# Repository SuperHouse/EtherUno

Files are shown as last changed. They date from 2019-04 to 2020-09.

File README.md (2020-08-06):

SuperHouse EtherUNO
===================

The EtherUNO is a 100% Arduino Compatible Board, based on the Arduino
UNO reference design, but with improvements and updates for ease of use,
cost, and getting started. It also includes on-board Ethernet with PoE
(Power-over-Ethernet) support and uses a USB-C socket.

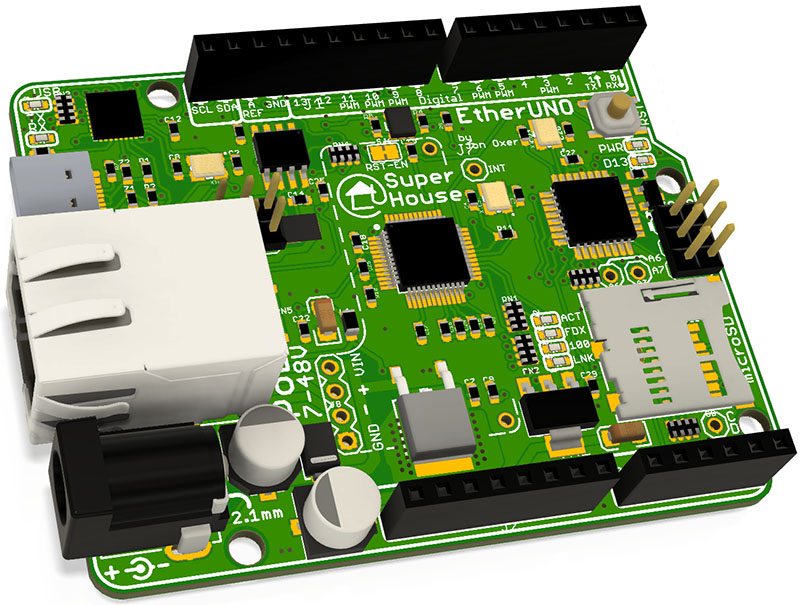
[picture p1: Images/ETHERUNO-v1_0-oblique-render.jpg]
EtherUNO


Features:

 * LEDs visible on the edge
 * USB-C Connector
 * I2C MAC address ROM
 * Overlay guide where you need it (both top and bottom)
 * D13 pin works for everything
 * RX pin biased
 * Mounting holes

More information is available at:

  https://www.superhouse.tv/eu

Hardware
--------
The "Hardware" directory contains the PCB design as an EAGLE project.
EAGLE PCB design software is available from Autodesk free for
non-commercial use.

Credits
-------
 * Jonathan Oxer <jon@oxer.com.au>

 The EtherUNO is based on the EtherTen, which was designed by Jonathan
 Oxer and Marc Alexander.

License
-------
Copyright 2020 SuperHouse Automation Pty Ltd  www.superhouse.tv  

The hardware portion of this project is licensed under the TAPR Open
Hardware License (www.tapr.org/OHL). The "license" folder within this
repository contains a copy of this license in plain text format.

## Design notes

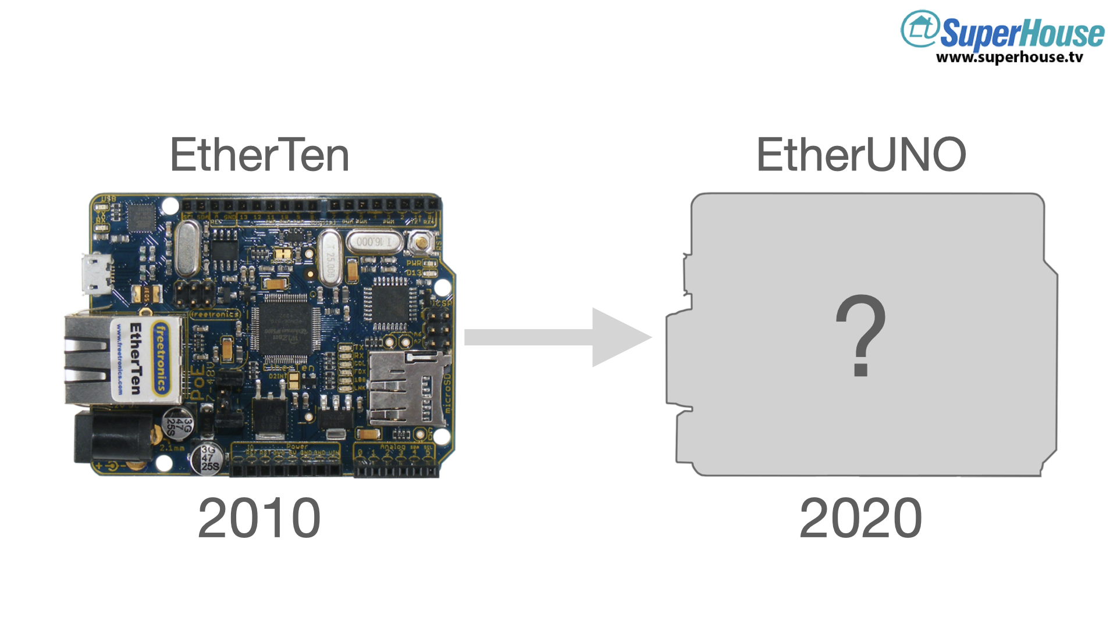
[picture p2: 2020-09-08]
Images/ETHERUNO-teaser/ETHERUNO-teaser.002.jpeg

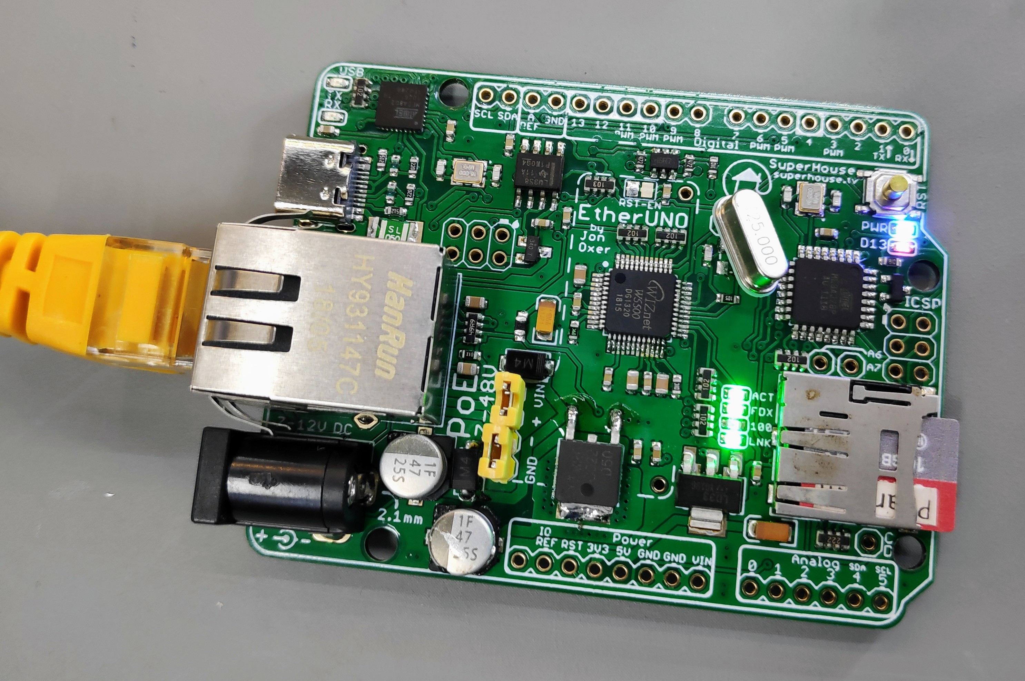
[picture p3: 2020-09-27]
Images/2020-09-27 17.50.06.jpg

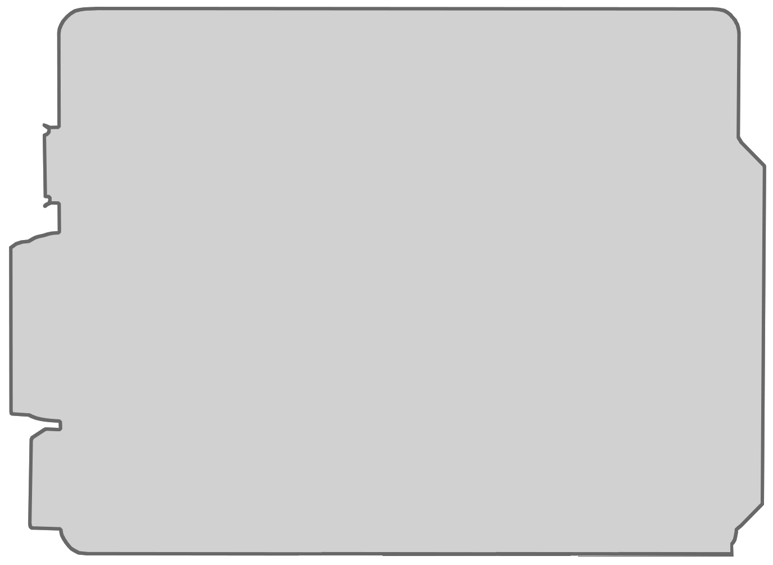
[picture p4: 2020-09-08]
Images/ET-v3_0-outline.png

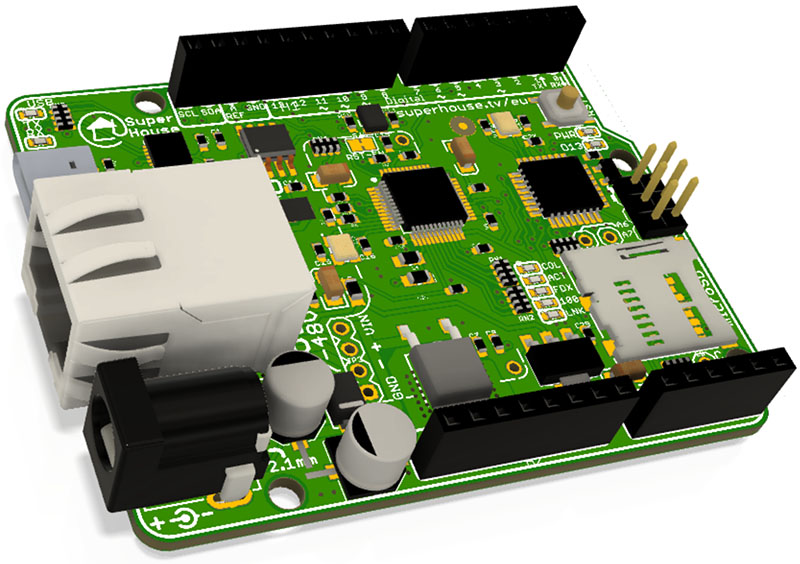
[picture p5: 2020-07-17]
Images/ETHERUNO-v4_0-oblique-render.jpg

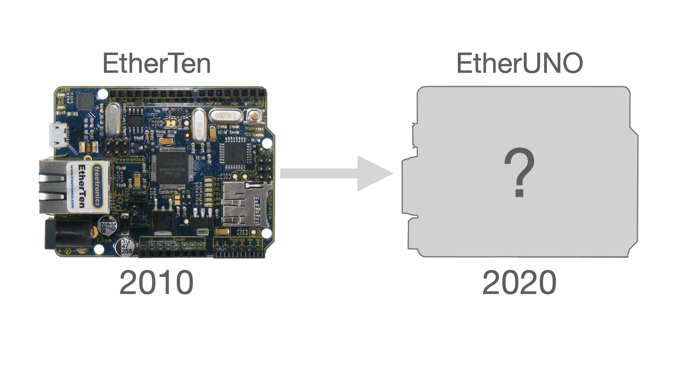
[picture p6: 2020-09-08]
Images/ETHERUNO-teaser/ETHERUNO-teaser.001.jpeg

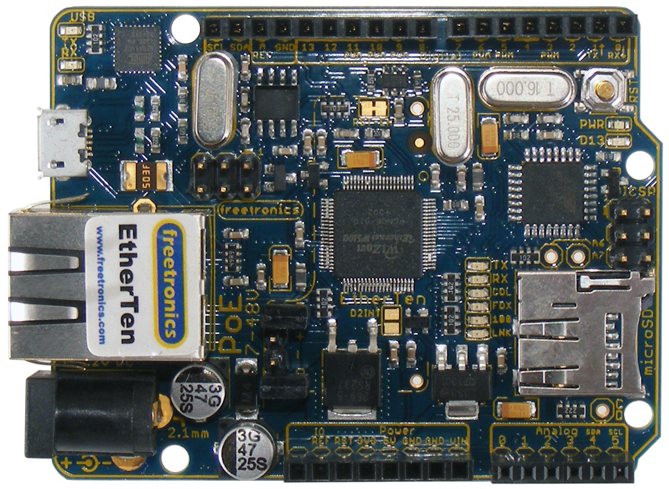
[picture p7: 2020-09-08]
Images/ET-v3_0-top.png

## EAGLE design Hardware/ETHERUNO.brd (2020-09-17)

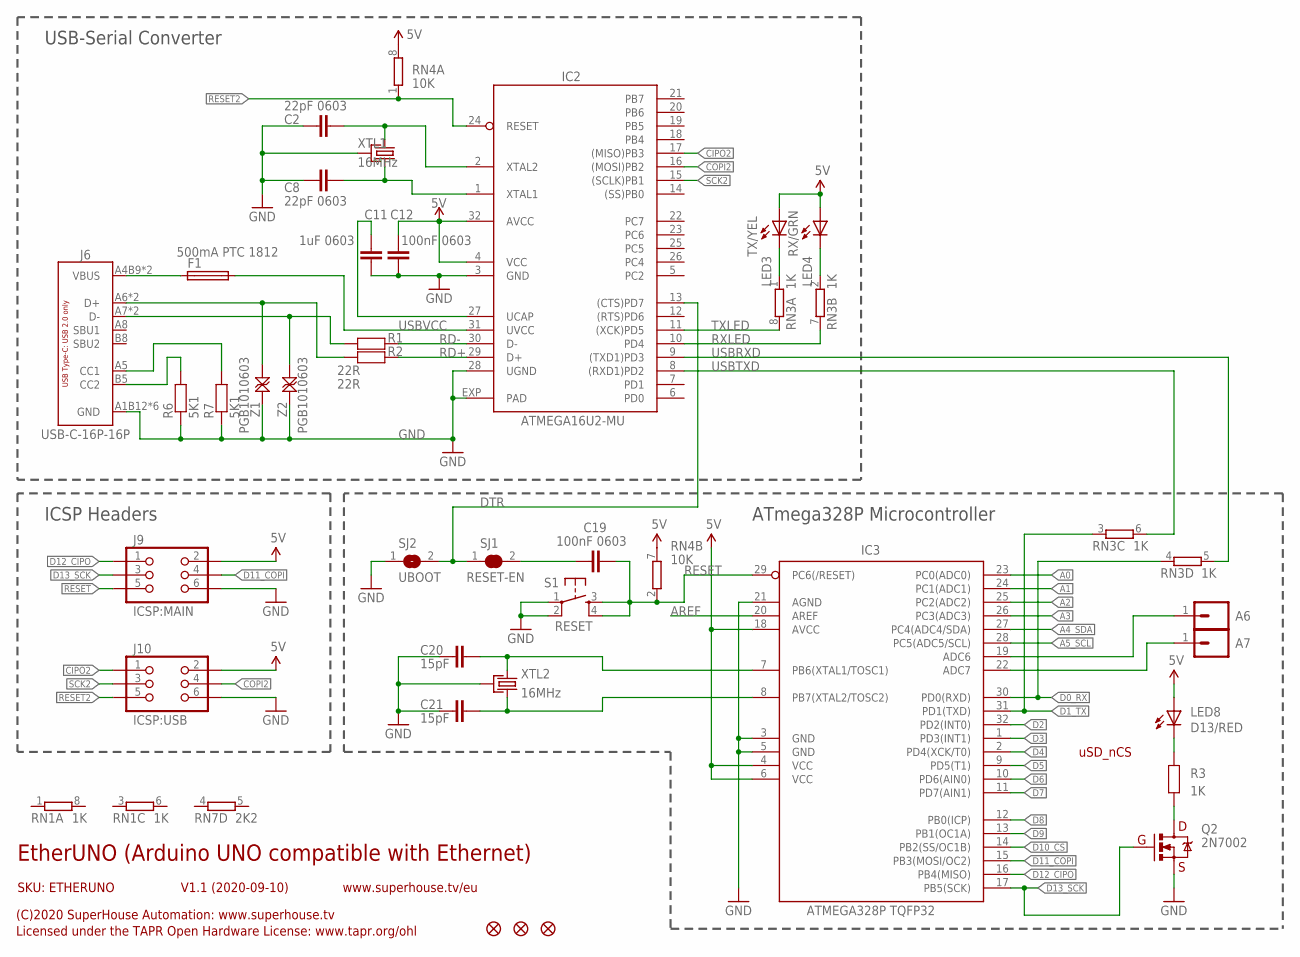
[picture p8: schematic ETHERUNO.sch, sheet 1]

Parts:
A6: A6; 1X01
A7: A7; 1X01
C2, C8: 22pF 0603; C0603
C11: 1uF 0603; C0603
C12, C19: 100nF 0603; C0603
C20, C21: 15pF; C0603
F1: 500mA PTC 1812; 1812
FID1, FID2, FID3: FIDUCIAL1X2.5; FIDUCIAL-1X2.5
IC2: ATMEGA16U2-MU; ATMEL_QFN32
IC3: ATMEGA328P TQFP32; TQFP32-08
J6: USB-C-16P-16P; USB-C-16P
J9: ICSP:MAIN; 2X03-ICSP
J10: ICSP:USB; 2X03-ICSP
LED3: TX/YEL; LED-0603
LED4: RX/GRN; LED-0603
LED8: D13/RED; LED-0603
Q2: 2N7002; SOT23-3
R1, R2: 22R; R0603
R3: 1K; R0603
R6, R7: 5K1; R0603
RN1, RN3: 1K; CAY16
RN4: 10K; CAY16
RN7: 2K2; CAY16
S1: RESET; TACTILE_SMT-6MM
SJ1: RESET-EN; SJC
SJ2: UBOOT; SJ
XTL1, XTL2: 16MHz; CRYSTAL-SMD-3X2
Z1, Z2: PGB1010603; TVS0603

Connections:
5V: C12.1, IC2.4 (VCC), IC2.32 (AVCC), IC3.4 (VCC), IC3.6 (VCC), IC3.18 (AVCC), J9.2, J10.2, LED3.A, LED4.A, LED8.A, RN4.7 (2), RN4.8 (2); also elsewhere on the board
A0: IC3.23 (PC0(ADC0)); also elsewhere on the board
A1: IC3.24 (PC1(ADC1)); also elsewhere on the board
A2: IC3.25 (PC2(ADC2)); also elsewhere on the board
A3: IC3.26 (PC3(ADC3)); also elsewhere on the board
A4_SDA: IC3.27 (PC4(ADC4/SDA)); also elsewhere on the board
A5_SCL: IC3.28 (PC5(ADC5/SCL)); also elsewhere on the board
AREF: IC3.20 (AREF); also elsewhere on the board
CIPO2: IC2.17 ((MISO)PB3), J10.1
COPI2: IC2.16 ((MOSI)PB2), J10.4
D0_RX: IC3.30 (PD0(RXD)), RN3.4 (1); also elsewhere on the board
D1_TX: IC3.31 (PD1(TXD)), RN3.3 (1); also elsewhere on the board
D2: IC3.32 (PD2(INT0)); also elsewhere on the board
D3: IC3.1 (PD3(INT1)); also elsewhere on the board
D4: IC3.2 (PD4(XCK/T0)); also elsewhere on the board
D5: IC3.9 (PD5(T1)); also elsewhere on the board
D6: IC3.10 (PD6(AIN0)); also elsewhere on the board
D7: IC3.11 (PD7(AIN1)); also elsewhere on the board
D8: IC3.12 (PB0(ICP)); also elsewhere on the board
D9: IC3.13 (PB1(OC1A)); also elsewhere on the board
D10_CS: IC3.14 (PB2(SS/OC1B)); also elsewhere on the board
D11_COPI: IC3.15 (PB3(MOSI/OC2)), J9.4; also elsewhere on the board
D12_CIPO: IC3.16 (PB4(MISO)), J9.1; also elsewhere on the board
D13_SCK: IC3.17 (PB5(SCK)), J9.3, Q2.1 (G); also elsewhere on the board
DTR: IC2.13 ((CTS)PD7), SJ1.1, SJ2.2
GND: C2.1, C8.1, C11.2, C12.2, C20.1, C21.1, IC2.3 (GND), IC2.28 (UGND), IC2.EXP (PAD), IC3.3 (GND), IC3.5 (GND), IC3.21 (AGND), J6.A1B12 (GND), J6.A12B1 (GND), J6.FIX1 (GND), J6.FIX2 (GND), J6.FIX3 (GND), J6.FIX4 (GND), J9.6, J10.6, Q2.2 (S), R6.1, R7.1, S1.1, S1.2, SJ2.1, XTL1.2 (GND), XTL1.4 (GND), XTL2.2 (GND), XTL2.4 (GND), Z1.2, Z2.2; also elsewhere on the board
unnamed: C20.2, IC3.7 (PB6(XTAL1/TOSC1)), XTL2.1
unnamed: C19.1, SJ1.2
unnamed: LED8.C, R3.2
unnamed: Q2.3 (D), R3.1
unnamed: C21.2, IC3.8 (PB7(XTAL2/TOSC2)), XTL2.3 (2)
unnamed: C8.2, IC2.1 (XTAL1), XTL1.3 (2)
unnamed: J6.B5 (CC2), R6.2
unnamed: LED4.C, RN3.2 (1)
unnamed: LED3.C, RN3.1
unnamed: J6.A6 (D+), J6.B6 (D+), R2.2, Z1.1
unnamed: J6.A7 (D-), J6.B7 (D-), R1.2, Z2.1
unnamed: A7.1, IC3.22 (ADC7)
unnamed: A6.1, IC3.19 (ADC6)
unnamed: J6.A5 (CC1), R7.2
unnamed: C2.2, IC2.2 (XTAL2), XTL1.1
unnamed: F1.1, J6.A4B9 (VBUS), J6.A9B4 (VBUS)
unnamed: C11.1, IC2.27 (UCAP)
RD+: IC2.29 (D+), R2.1
RD-: IC2.30 (D-), R1.1
RESET: C19.2, IC3.29 (PC6(/RESET)), J9.5, RN4.2 (1), S1.3, S1.4; also elsewhere on the board
RESET2: IC2.24 (RESET), J10.5, RN4.1
RXLED: IC2.10 (PD4), RN3.7 (2)
SCK2: IC2.15 ((SCLK)PB1), J10.3
TXLED: IC2.11 ((XCK)PD5), RN3.8 (2)
USBRXD: IC2.9 ((TXD1)PD3), RN3.5 (2)
USBTXD: IC2.8 ((RXD1)PD2), RN3.6 (2)
USBVCC: F1.2, IC2.31 (UVCC); also elsewhere on the board

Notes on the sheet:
uSD_nCS
EtherUNO (Arduino UNO compatible with Ethernet)
SKU: ETHERUNO
(C)2020 SuperHouse Automation: www.superhouse.tv
Licensed under the TAPR Open Hardware License: www.tapr.org/ohl
www.superhouse.tv/eu
V1.1 (2020-09-10)
ICSP Headers
USB-Serial Converter
ATmega328P Microcontroller

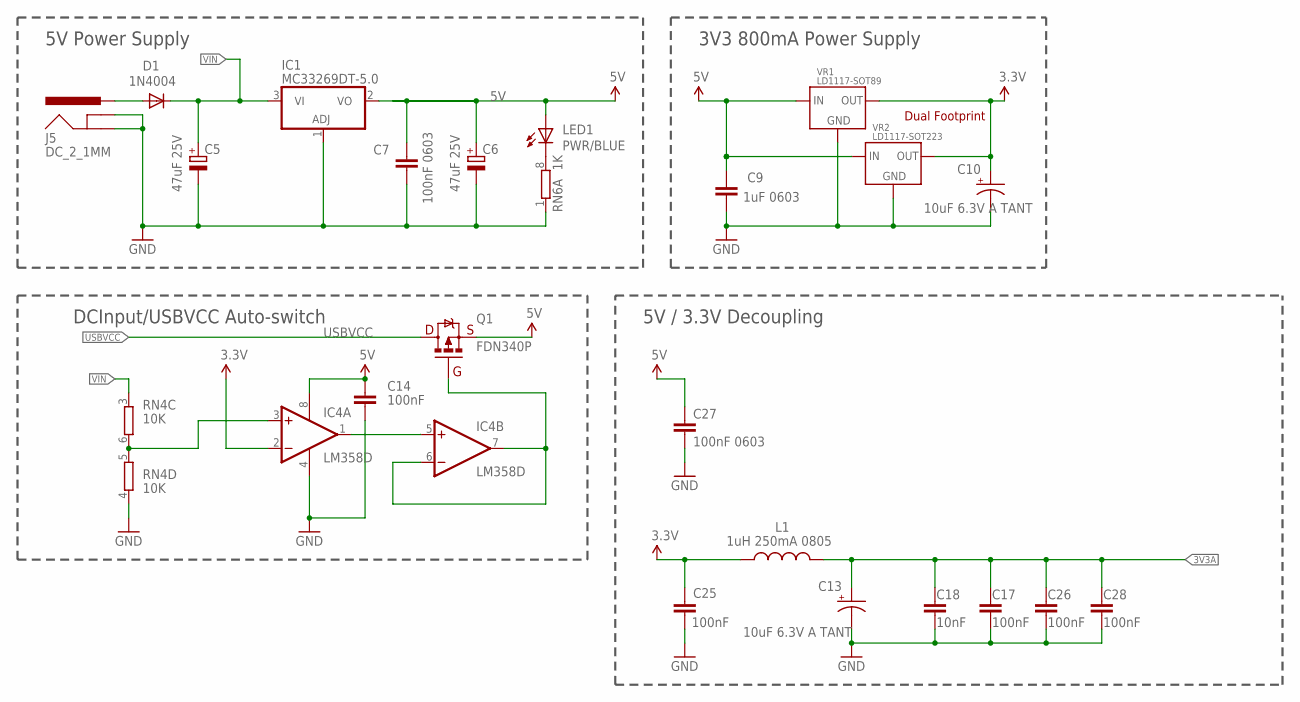
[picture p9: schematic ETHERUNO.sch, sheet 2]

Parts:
C5, C6: 47uF 25V; PANASONIC_D
C7, C27: 100nF 0603; C0603
C9: 1uF 0603; C0603
C10, C13: 10uF 6.3V A TANT; EIA3216
C14, C17, C25, C26, C28: 100nF; C0603
C18: 10nF; C0603
D1: 1N4004; SMA-DIODE
IC1: MC33269DT-5.0; DPACK
IC4: LM358D; SO08
J5: DC_2_1MM; POWER_JACK_SLOTS
L1: 1uH 250mA 0805; L2012C
LED1: PWR/BLUE; LED-0603
Q1: FDN340P; SOT23
RN4: 10K; CAY16
RN6: 1K; CAY16
VR1: LD1117-SOT89; SOT89
VR2: LD1117-SOT223; SOT-223

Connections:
3.3V: C10.A (+), C25.1, IC4.2 (-IN), L1.1, VR1.2 (OUT), VR1.4 (OUT), VR2.2 (OUT), VR2.4 (OUT); also elsewhere on the board
3V3A: C13.A (+), C17.1, C18.1, C26.1, C28.1, L1.2; also elsewhere on the board
5V: C6.+, C7.1, C9.1, C14.1, C27.1, IC1.2 (VO), IC4.8 (V+), LED1.A, Q1.2 (S), VR1.3 (IN), VR2.3 (IN); also elsewhere on the board
GND: C5.-, C6.-, C7.2, C9.2, C10.C (-), C13.C (-), C14.2, C17.2, C18.2, C25.2, C26.2, C27.2, C28.2, IC1.1 (ADJ), IC4.4 (V-), J5.GND, J5.GNDBREAK, RN4.4 (1), RN6.1, VR1.1 (GND), VR2.1 (GND); also elsewhere on the board
unnamed: IC4.3 (+IN), RN4.5 (2), RN4.6 (2)
unnamed: LED1.C, RN6.8 (2)
unnamed: IC4.6 (-IN), IC4.7 (OUT), Q1.1 (G)
unnamed: IC4.1 (OUT), IC4.5 (+IN)
unnamed: D1.A, J5.PWR
USBVCC: Q1.3 (D); also elsewhere on the board
VIN: C5.+, D1.C, IC1.3 (VI), RN4.3 (1); also elsewhere on the board

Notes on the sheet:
3V3 800mA Power Supply
Dual Footprint
5V Power Supply
DCInput/USBVCC Auto-switch
5V / 3.3V Decoupling

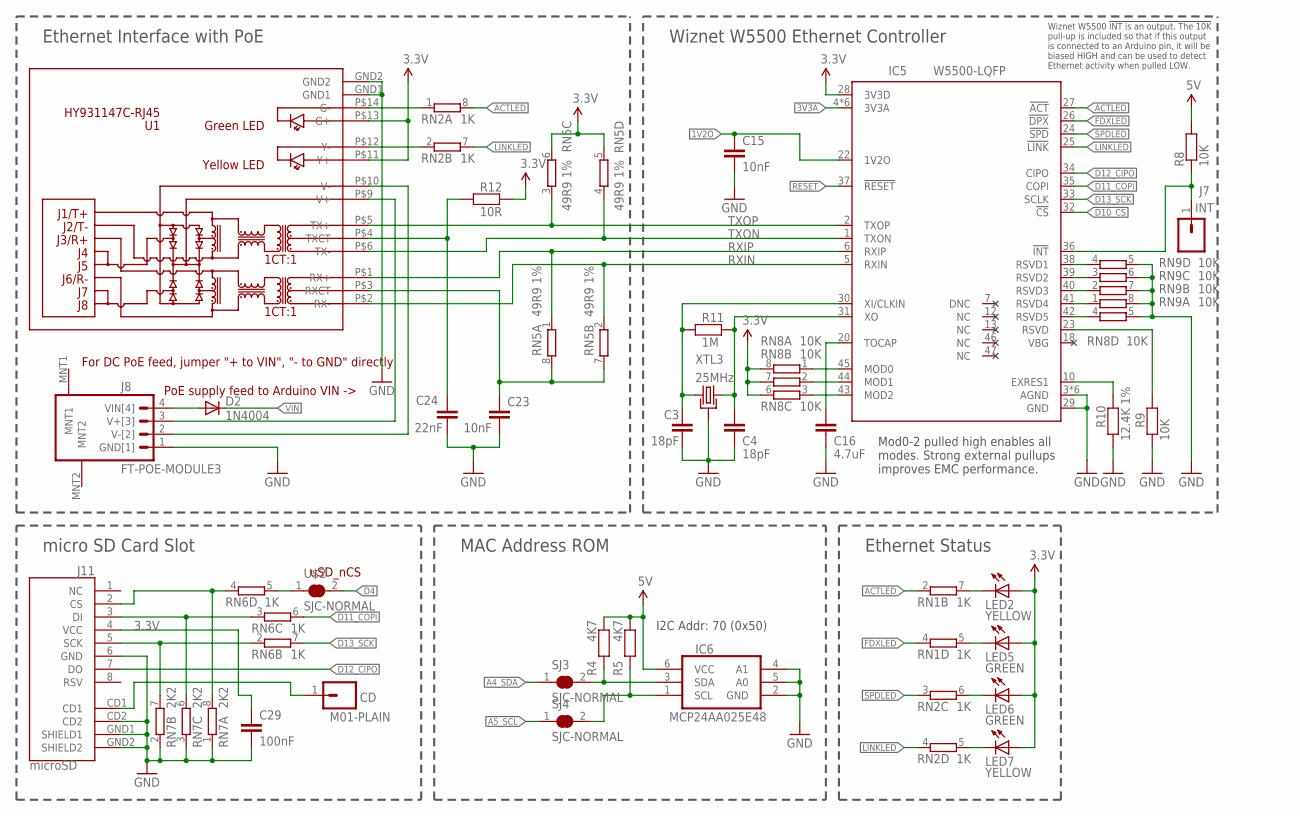
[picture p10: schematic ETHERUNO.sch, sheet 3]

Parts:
C3, C4: 18pF; C0603
C15, C23: 10nF; C0603
C16: 4.7uF; C0603
C24: 22nF; C0603
C29: 100nF; C0603
CD: M01-PLAIN; 1X01
D2: 1N4004; SMA-DIODE
IC5: W5500-LQFP; LQFP48
IC6: MCP24AA025E48; SOT23-6
J7: INT; 1X01
J8: FT-POE-MODULE3; FT-POE-MODULE-NOLABEL
J11: microSD; MICRO-SD-SOCKET-PP
LED2, LED7: YELLOW; LED-0603
LED5, LED6: GREEN; LED-0603
R4, R5: 4K7; R0603
R8, R9: 10K; R0603
R10: 12.4K 1%; R0603
R11: 1M; R0603
R12: 10R; R0603
RN1, RN2, RN6: 1K; CAY16
RN5: 49R9 1%; CAY16
RN7: 2K2; CAY16
RN8, RN9: 10K; CAY16
SJ3, SJ4: SJC-NORMAL; SJC
U1: HY931147C-RJ45; HY931147C
U$2: SJC-NORMAL; SJC
XTL3: 25MHz; CRYSTAL-SMD-3X2

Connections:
1V2O: C15.1, IC5.22 (1V2O)
3.3V: C29.1, IC5.28 (3V3D), J11.4 (VCC), LED2.A, LED5.A, LED6.A, LED7.A, R12.1, RN5.5 (2), RN5.6 (2), RN8.6 (2), RN8.7 (2), RN8.8 (2), U1.P$11 (Y+), U1.P$13 (G+); also elsewhere on the board
3V3A: IC5.4 (3V3A), IC5.8 (3V3A), IC5.11 (3V3A), IC5.15 (3V3A), IC5.17 (3V3A), IC5.21 (3V3A); also elsewhere on the board
5V: IC6.6 (VCC), R4.1, R5.1, R8.2; also elsewhere on the board
A4_SDA: SJ3.1; also elsewhere on the board
A5_SCL: SJ4.1; also elsewhere on the board
ACTLED: IC5.27 (!ACT), RN1.2 (1), RN2.8 (2)
D4: U$2.2; also elsewhere on the board
D10_CS: IC5.32 (!CS); also elsewhere on the board
D11_COPI: IC5.35 (COPI), RN6.6 (2); also elsewhere on the board
D12_CIPO: IC5.34 (CIPO), J11.7 (DO); also elsewhere on the board
D13_SCK: IC5.33 (SCLK), RN6.7 (2); also elsewhere on the board
FDXLED: IC5.26 (!DPX), RN1.4 (1)
GND: C3.2, C4.2, C15.2, C16.2, C23.2, C24.2, C29.2, IC5.3 (AGND), IC5.9 (AGND), IC5.14 (AGND), IC5.16 (AGND), IC5.19 (AGND), IC5.29 (GND), IC5.48 (AGND), IC6.2 (GND), IC6.4 (A1), IC6.5 (A0), J8.1 (GND[1]), J11.6 (GND), J11.CD2, J11.GND1 (SHIELD1), J11.GND2 (SHIELD2), R9.2, R10.2, RN7.1, RN7.2 (1), RN7.3 (1), RN8.5 (2), RN9.5 (2), RN9.6 (2), RN9.7 (2), RN9.8 (2), U1.GND1, U1.GND2, XTL3.2 (GND), XTL3.4 (GND); also elsewhere on the board
LINKLED: IC5.25 (!LINK), RN2.4 (1), RN2.7 (2)
unnamed: C23.1, RN5.7 (2), RN5.8 (2), U1.P$3 (RXCT)
unnamed: IC6.1 (SCL), R5.2, SJ4.2
unnamed: C4.1, IC5.31 (XO), R11.1, XTL3.3 (2)
unnamed: D2.A, J8.4 (VIN[4])
unnamed: J11.2 (CS), RN6.4 (1), RN7.8 (2)
unnamed: CD.1, J11.CD1
unnamed: J11.5 (SCK), RN6.2 (1), RN7.7 (2)
unnamed: J11.3 (DI), RN6.3 (1), RN7.6 (2)
unnamed: LED6.C, RN2.6 (2)
unnamed: C3.1, IC5.30 (XI/CLKIN), R11.2, XTL3.1
unnamed: LED7.C, RN2.5 (2)
unnamed: IC6.3 (SDA), R4.2, SJ3.2
unnamed: C16.1, IC5.20 (TOCAP)
unnamed: C24.1, R12.2, U1.P$4 (TXCT)
unnamed: IC5.10 (EXRES1), R10.1
unnamed: IC5.23 (RSVD), R9.1
unnamed: IC5.36 (!INT), J7.1, R8.1
unnamed: IC5.45 (MOD0), RN8.1
unnamed: IC5.44 (MOD1), RN8.2 (1)
unnamed: IC5.43 (MOD2), RN8.3 (1)
unnamed: IC5.42 (RSVD5), RN8.4 (1)
unnamed: IC5.41 (RSVD4), RN9.1
unnamed: IC5.40 (RSVD3), RN9.2 (1)
unnamed: IC5.39 (RSVD2), RN9.3 (1)
unnamed: IC5.38 (RSVD1), RN9.4 (1)
unnamed: RN6.5 (2), U$2.1
unnamed: RN2.1, U1.P$14 (G-)
unnamed: J8.3 (V+[3]), U1.P$9 (V+)
unnamed: J8.2 (V-[2]), U1.P$10 (V-)
unnamed: LED5.C, RN1.5 (2)
unnamed: LED2.C, RN1.7 (2)
unnamed: RN2.2 (1), U1.P$12 (Y-)
RESET: IC5.37 (!RESET); also elsewhere on the board
RXIN: IC5.5 (RXIN), RN5.2 (1), U1.P$2 (RX-)
RXIP: IC5.6 (RXIP), RN5.1, U1.P$1 (RX+)
SPDLED: IC5.24 (!SPD), RN2.3 (1)
TXON: IC5.1 (TXON), RN5.4 (1), U1.P$6 (TX-)
TXOP: IC5.2 (TXOP), RN5.3 (1), U1.P$5 (TX+)
VIN: D2.C; also elsewhere on the board

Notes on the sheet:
uSD_nCS
micro SD Card Slot
I2C Addr: 70 (0x50)
Ethernet Status
PoE supply feed to Arduino VIN ->
For DC PoE feed, jumper "+ to VIN", "- to GND" directly
Ethernet Interface with PoE
MAC Address ROM
Wiznet W5500 Ethernet Controller
Mod0-2 pulled high enables all modes. Strong external pullups improves EMC performance.
Wiznet W5500 !INT is an output. The 10K pull-up is included so that if this output is connected to an Arduino pin, it will be biased HIGH and can be used to detect Ethernet activity when pulled LOW.

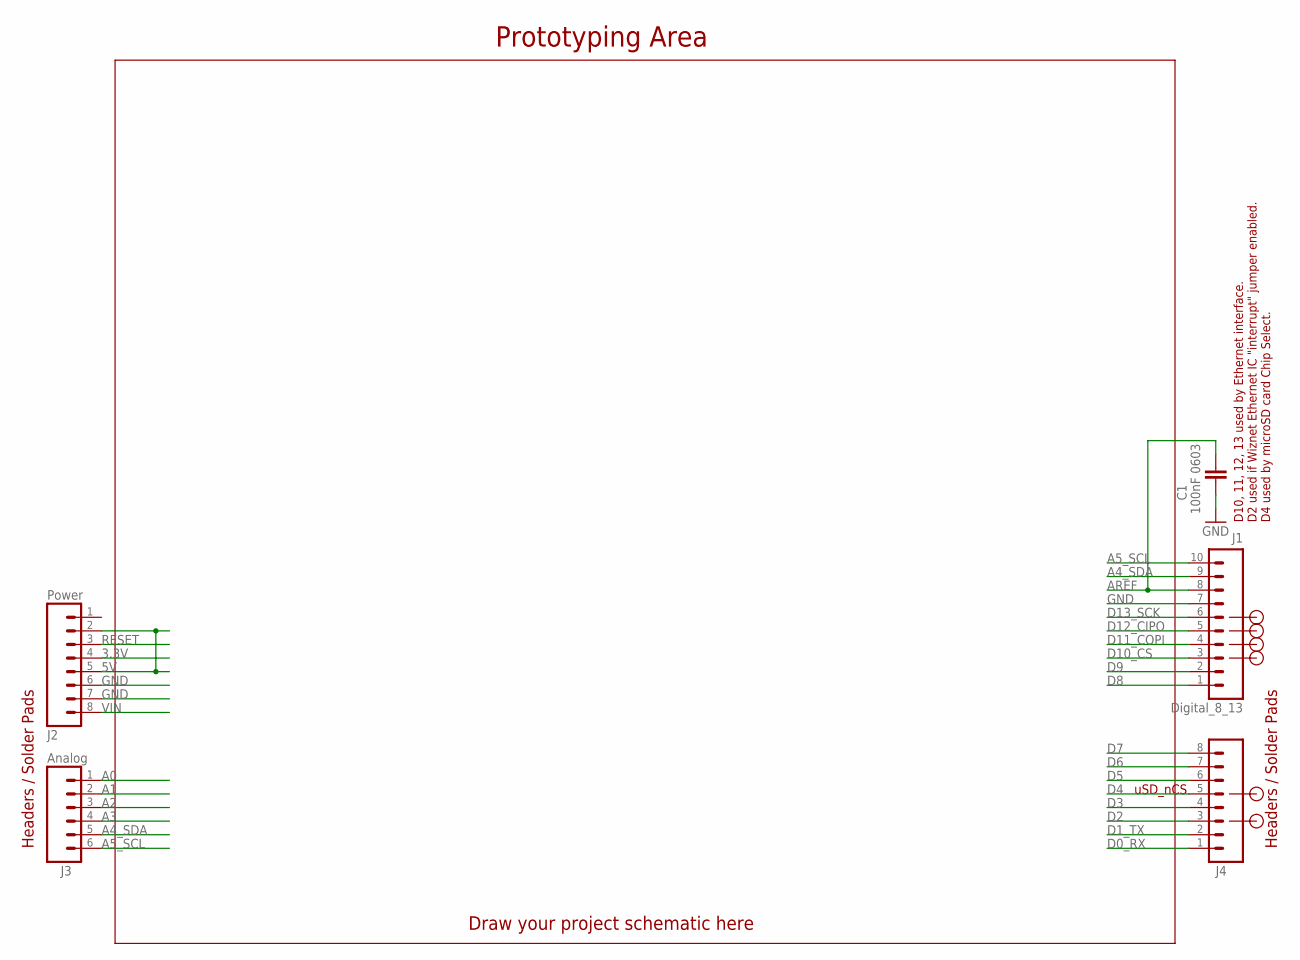
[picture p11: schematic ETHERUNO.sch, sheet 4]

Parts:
C1: 100nF 0603; C0603
J1: Digital_8_13; 1X10-S
J2: Power; 1X08-S
J3: Analog; 1X06-S
J4: Digital_0_7; 1X08-S

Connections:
3.3V: J2.4; also elsewhere on the board
5V: J2.2, J2.5; also elsewhere on the board
A0: J3.1; also elsewhere on the board
A1: J3.2; also elsewhere on the board
A2: J3.3; also elsewhere on the board
A3: J3.4; also elsewhere on the board
A4_SDA: J1.9, J3.5; also elsewhere on the board
A5_SCL: J1.10, J3.6; also elsewhere on the board
AREF: C1.1, J1.8; also elsewhere on the board
D0_RX: J4.1; also elsewhere on the board
D1_TX: J4.2; also elsewhere on the board
D2: J4.3; also elsewhere on the board
D3: J4.4; also elsewhere on the board
D4: J4.5; also elsewhere on the board
D5: J4.6; also elsewhere on the board
D6: J4.7; also elsewhere on the board
D7: J4.8; also elsewhere on the board
D8: J1.1; also elsewhere on the board
D9: J1.2; also elsewhere on the board
D10_CS: J1.3; also elsewhere on the board
D11_COPI: J1.4; also elsewhere on the board
D12_CIPO: J1.5; also elsewhere on the board
D13_SCK: J1.6; also elsewhere on the board
GND: C1.2, J1.7, J2.6, J2.7; also elsewhere on the board
RESET: J2.3; also elsewhere on the board
VIN: J2.8; also elsewhere on the board

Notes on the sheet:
Prototyping Area
Headers / Solder Pads
Draw your project schematic here
D10, 11, 12, 13 used by Ethernet interface.
D2 used if Wiznet Ethernet IC "interrupt" jumper enabled.
uSD_nCS
D4 used by microSD card Chip Select.

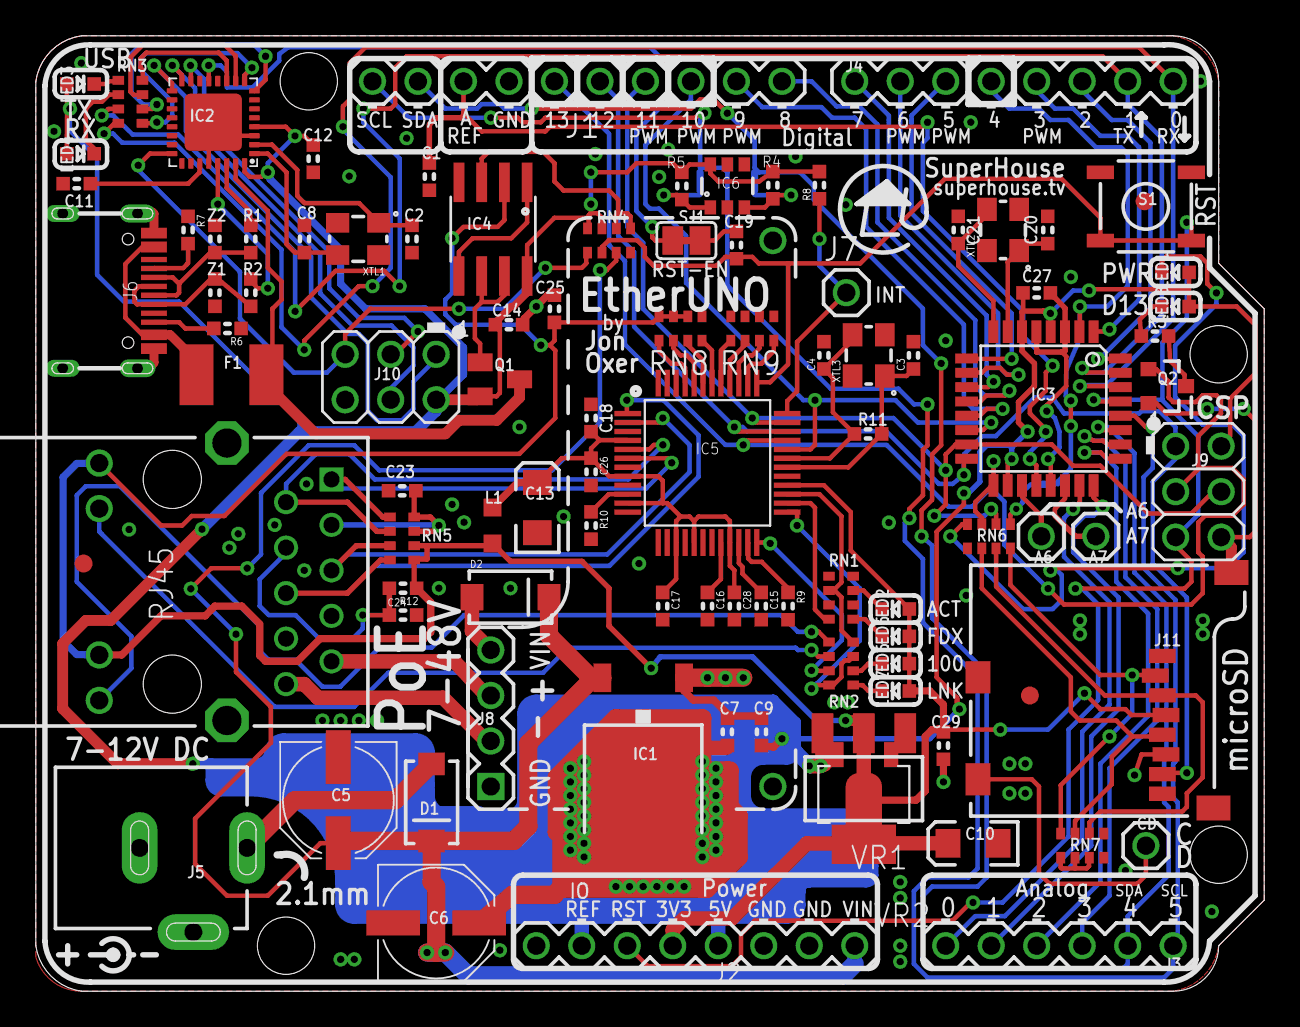
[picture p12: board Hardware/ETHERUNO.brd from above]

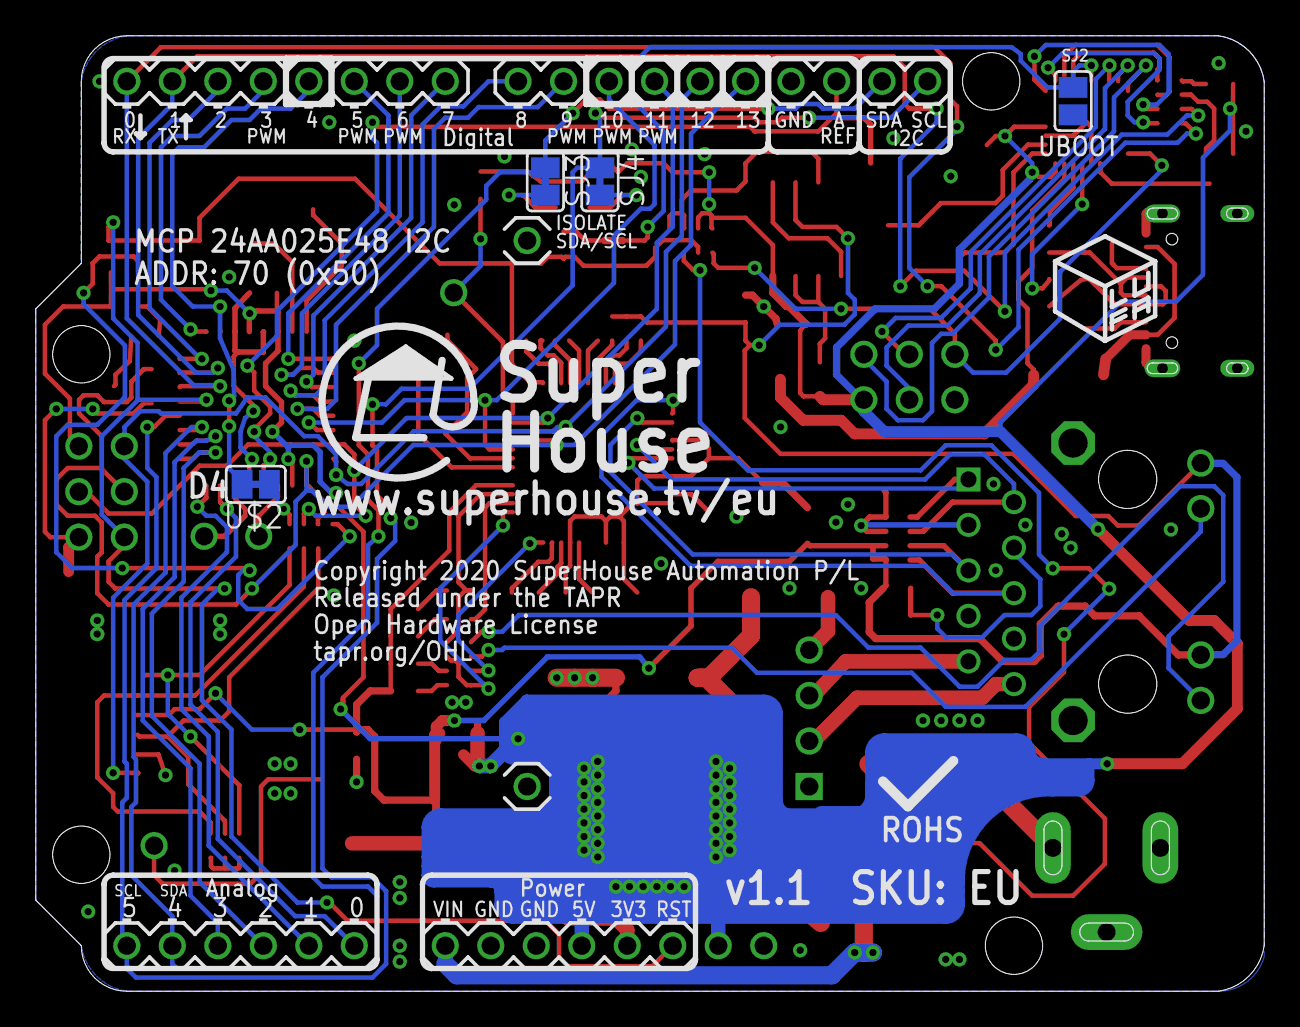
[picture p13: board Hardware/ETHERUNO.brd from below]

Board: 2 copper layers, 68.6 x 53.3 mm, 100 parts (4 on the bottom side), 102 nets.

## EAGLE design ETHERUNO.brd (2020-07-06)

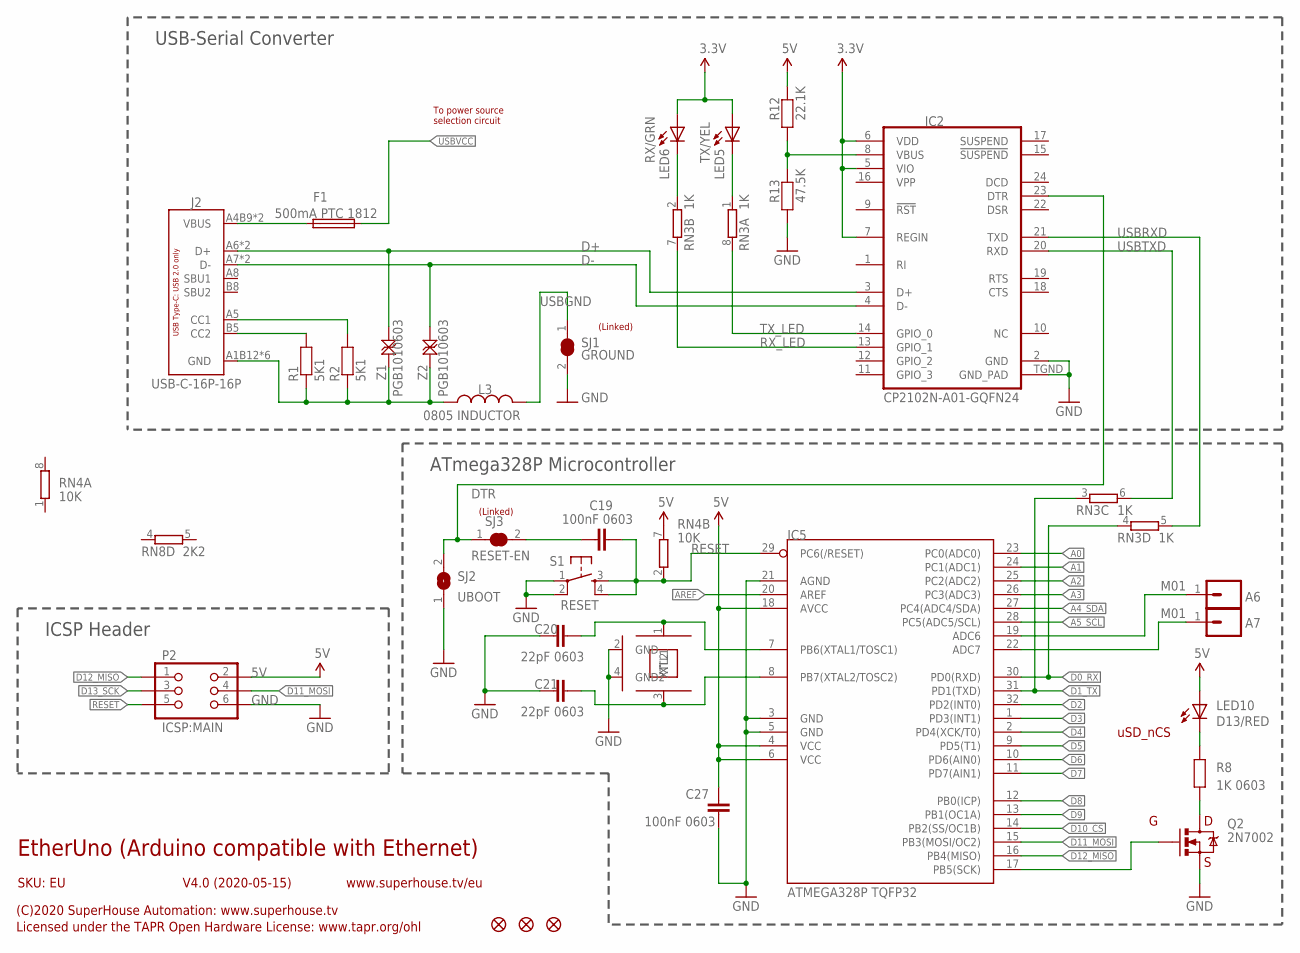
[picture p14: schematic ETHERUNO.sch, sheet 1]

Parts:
A6, A7: M01; 1X01
C19, C27: 100nF 0603; C0603
C20, C21: 22pF 0603; C0603
F1: 500mA PTC 1812; 1812
FID1, FID2, FID3: FIDUCIAL1X2.5; FIDUCIAL-1X2.5
IC2: CP2102N-A01-GQFN24; QFN-24
IC5: ATMEGA328P TQFP32; TQFP32-08
J2: USB-C-16P-16P; USB-C-16P
L3: 0805 INDUCTOR; 0805-LARGE
LED5: TX/YEL; LED-0603
LED6: RX/GRN; LED-0603
LED10: D13/RED; LED-0603
P2: ICSP:MAIN; 2X03-ICSP
Q2: 2N7002; SOT23-3
R1, R2: 5K1; R0603
R8: 1K 0603; R0603
R12: 22.1K; R0603
R13: 47.5K; R0603
RN3: 1K; CAY16
RN4: 10K; CAY16
RN8: 2K2; CAY16
S1: RESET; TACTILE_SMT-6MM
SJ1: GROUND; SJC
SJ2: UBOOT; SJ
SJ3: RESET-EN; SJC
U$19: CRYSTAL-GND3X2; CRYSTAL-SMD-3X2
Z1, Z2: PGB1010603; TVS0603

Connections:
3.3V: IC2.5 (VIO), IC2.6 (VDD), IC2.7 (REGIN), LED5.A, LED6.A; also elsewhere on the board
5V: C27.1, IC5.4 (VCC), IC5.6 (VCC), IC5.18 (AVCC), LED10.A, P2.2, R12.2, RN4.7 (2); also elsewhere on the board
A0: IC5.23 (PC0(ADC0)); also elsewhere on the board
A1: IC5.24 (PC1(ADC1)); also elsewhere on the board
A2: IC5.25 (PC2(ADC2)); also elsewhere on the board
A3: IC5.26 (PC3(ADC3)); also elsewhere on the board
A4_SDA: IC5.27 (PC4(ADC4/SDA)); also elsewhere on the board
A5_SCL: IC5.28 (PC5(ADC5/SCL)); also elsewhere on the board
AREF: IC5.20 (AREF); also elsewhere on the board
D0_RX: IC5.30 (PD0(RXD)), RN3.4 (1); also elsewhere on the board
D1_TX: IC5.31 (PD1(TXD)), RN3.3 (1); also elsewhere on the board
D2: IC5.32 (PD2(INT0)); also elsewhere on the board
D3: IC5.1 (PD3(INT1)); also elsewhere on the board
D4: IC5.2 (PD4(XCK/T0)); also elsewhere on the board
D5: IC5.9 (PD5(T1)); also elsewhere on the board
D6: IC5.10 (PD6(AIN0)); also elsewhere on the board
D7: IC5.11 (PD7(AIN1)); also elsewhere on the board
D8: IC5.12 (PB0(ICP)); also elsewhere on the board
D9: IC5.13 (PB1(OC1A)); also elsewhere on the board
D10_CS: IC5.14 (PB2(SS/OC1B)); also elsewhere on the board
D11_MOSI: IC5.15 (PB3(MOSI/OC2)), P2.4; also elsewhere on the board
D12_MISO: IC5.16 (PB4(MISO)), P2.1; also elsewhere on the board
D13_SCK: IC5.17 (PB5(SCK)), P2.3, Q2.1 (G); also elsewhere on the board
D+: IC2.3 (D+), J2.A6 (D+), J2.B6 (D+), Z1.1
D-: IC2.4 (D-), J2.A7 (D-), J2.B7 (D-), Z2.1
DTR: IC2.23 (DTR), SJ2.2, SJ3.1
GND: C20.1, C21.1, C27.2, IC2.2 (GND), IC2.TGND (GND_PAD), IC5.3 (GND), IC5.5 (GND), IC5.21 (AGND), P2.6, Q2.2 (S), R13.1, S1.1, S1.2, SJ1.2, SJ2.1, U$19.2 (GND), U$19.4 (GND2); also elsewhere on the board
unnamed: C20.2, IC5.7 (PB6(XTAL1/TOSC1)), U$19.1 (XTL1)
unnamed: C19.1, SJ3.2
unnamed: LED10.C, R8.2
unnamed: Q2.3 (D), R8.1
unnamed: C21.2, IC5.8 (PB7(XTAL2/TOSC2)), U$19.3 (XTL2)
unnamed: J2.A1B12 (GND), J2.A12B1 (GND), J2.FIX1 (GND), J2.FIX2 (GND), J2.FIX3 (GND), J2.FIX4 (GND), L3.1, R1.1, R2.1, Z1.2, Z2.2
unnamed: J2.B5 (CC2), R1.2
unnamed: LED6.C, RN3.2 (1)
unnamed: LED5.C, RN3.1
unnamed: A7.1, IC5.22 (ADC7)
unnamed: A6.1, IC5.19 (ADC6)
unnamed: J2.A5 (CC1), R2.2
unnamed: IC2.8 (VBUS), R12.1, R13.2
unnamed: F1.1, J2.A4B9 (VBUS), J2.A9B4 (VBUS)
RESET: C19.2, IC5.29 (PC6(/RESET)), P2.5, RN4.2 (1), S1.3, S1.4; also elsewhere on the board
RX_LED: IC2.13 (GPIO_1), RN3.7 (2)
TX_LED: IC2.14 (GPIO_0), RN3.8 (2)
USBGND: L3.2, SJ1.1
USBRXD: IC2.21 (TXD), RN3.5 (2)
USBTXD: IC2.20 (RXD), RN3.6 (2)
USBVCC: F1.2; also elsewhere on the board

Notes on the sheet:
uSD_nCS
(Linked)
EtherUno (Arduino compatible with Ethernet)
SKU: EU
(C)2020 SuperHouse Automation: www.superhouse.tv
Licensed under the TAPR Open Hardware License: www.tapr.org/ohl
www.superhouse.tv/eu
V4.0 (2020-05-15)
USB-Serial Converter
ATmega328P Microcontroller
ICSP Header
To power source selection circuit

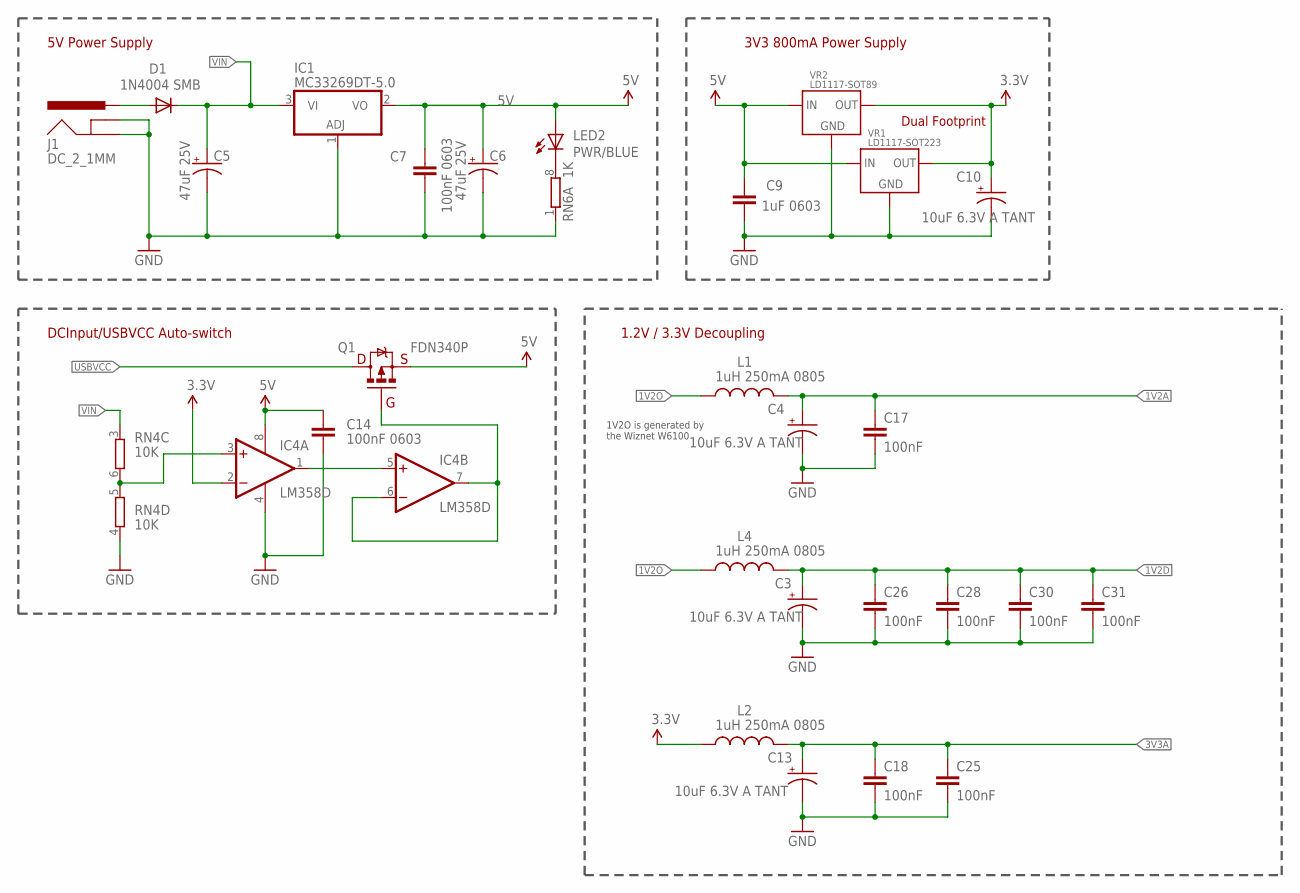
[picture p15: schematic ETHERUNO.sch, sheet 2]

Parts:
C3, C4, C10, C13: 10uF 6.3V A TANT; EIA3216
C5, C6: 47uF 25V; PANASONIC_D
C7, C14: 100nF 0603; C0603
C9: 1uF 0603; C0603
C17, C18, C25, C26, C28, C30, C31: 100nF; C0603
D1: 1N4004 SMB; SMA-DIODE
IC1: MC33269DT-5.0; DPACK
IC4: LM358D; SO08
J1: DC_2_1MM; POWER_JACK_SLOTS
L1, L2, L4: 1uH 250mA 0805; 0805-LARGE
LED2: PWR/BLUE; LED-0603
Q1: FDN340P; SOT23
RN4: 10K; CAY16
RN6: 1K; CAY16
VR1: LD1117-SOT223; SOT-223
VR2: LD1117-SOT89; SOT89

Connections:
1V2A: C4.A (+), C17.1, L1.2; also elsewhere on the board
1V2D: C3.A (+), C26.1, C28.1, C30.1, C31.1, L4.2; also elsewhere on the board
1V2O: L1.1, L4.1; also elsewhere on the board
3.3V: C10.A (+), IC4.2 (-IN), L2.1, VR1.2 (OUT), VR1.4 (OUT), VR2.2 (OUT), VR2.4 (OUT); also elsewhere on the board
3V3A: C13.A (+), C18.1, C25.1, L2.2; also elsewhere on the board
5V: C6.+, C7.1, C9.1, C14.1, IC1.2 (VO), IC4.8 (V+), LED2.A, Q1.2 (S), VR1.3 (IN), VR2.3 (IN); also elsewhere on the board
GND: C3.C (-), C4.C (-), C5.-, C6.-, C7.2, C9.2, C10.C (-), C13.C (-), C14.2, C17.2, C18.2, C25.2, C26.2, C28.2, C30.2, C31.2, IC1.1 (ADJ), IC4.4 (V-), J1.GND, J1.GNDBREAK, RN4.4 (1), RN6.1, VR1.1 (GND), VR2.1 (GND); also elsewhere on the board
unnamed: IC4.3 (+IN), RN4.5 (2), RN4.6 (2)
unnamed: LED2.C, RN6.8 (2)
unnamed: IC4.6 (-IN), IC4.7 (OUT), Q1.1 (G)
unnamed: IC4.1 (OUT), IC4.5 (+IN)
unnamed: D1.A, J1.PWR
USBVCC: Q1.3 (D); also elsewhere on the board
VIN: C5.+, D1.C, IC1.3 (VI), RN4.3 (1); also elsewhere on the board

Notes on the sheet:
5V Power Supply
DCInput/USBVCC Auto-switch
1.2V / 3.3V Decoupling
3V3 800mA Power Supply
Dual Footprint
1V2O is generated by the Wiznet W6100

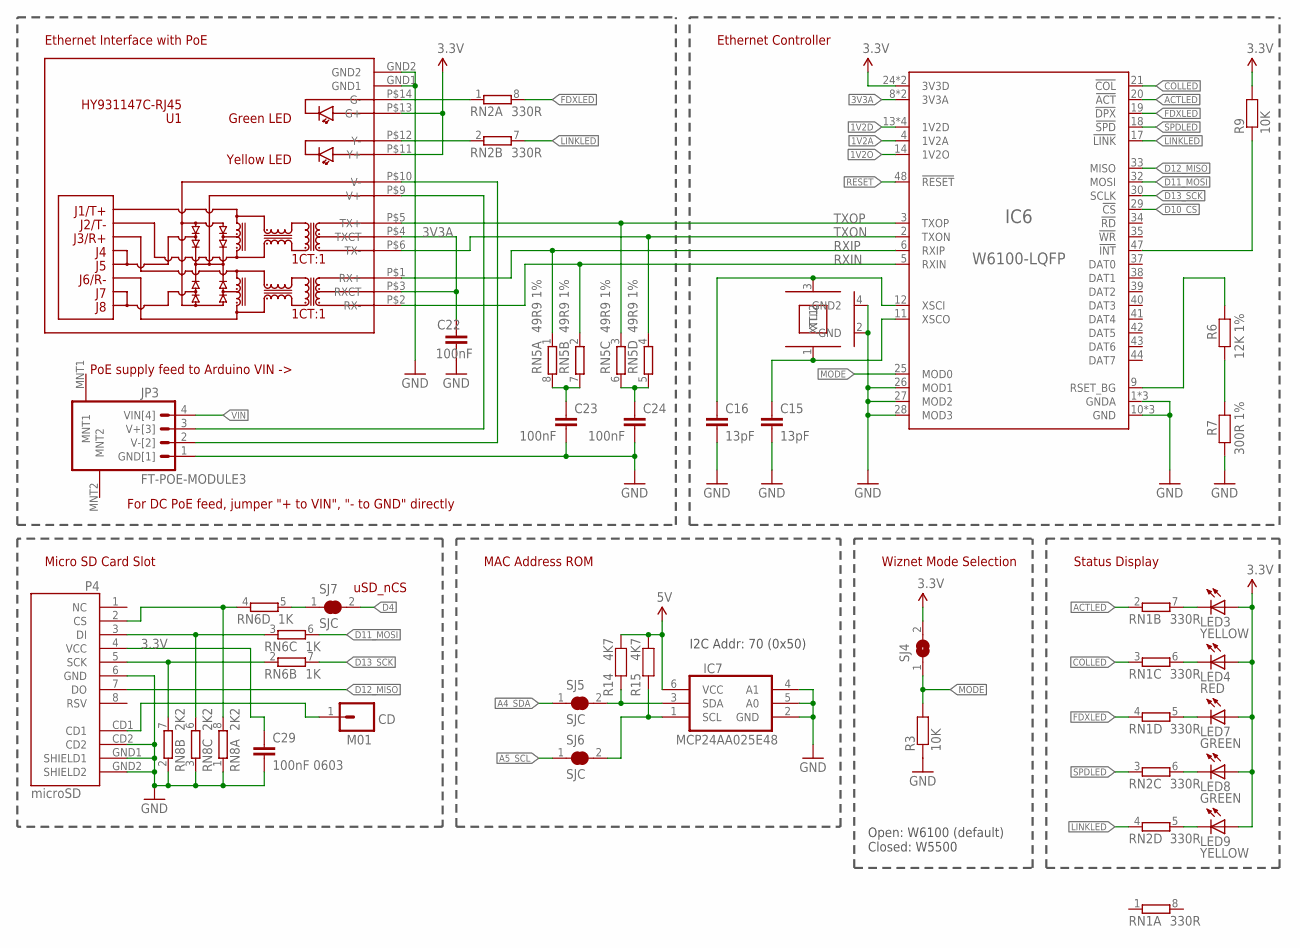
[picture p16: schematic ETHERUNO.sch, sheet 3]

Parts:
C15, C16: 13pF; C0603
C22, C23, C24: 100nF; C0603
C29: 100nF 0603; C0603
CD: M01; 1X01
IC6: W6100-LQFP; LQFP48
IC7: MCP24AA025E48; SOT23-6
JP3: FT-POE-MODULE3; FT-POE-MODULE-NOLABEL
LED3, LED9: YELLOW; LED-0603
LED4: RED; LED-0603
LED7, LED8: GREEN; LED-0603
P4: microSD; MICRO-SD-SOCKET-PP
R3, R9: 10K; R0603
R6: 12K 1%; R0603
R7: 300R 1%; R0603
R14, R15: 4K7; R0603
RN1, RN2: 330R; CAY16
RN5: 49R9 1%; CAY16
RN6: 1K; CAY16
RN8: 2K2; CAY16
SJ4: SJ-NORMAL; SJ
SJ5, SJ6, SJ7: SJC
U1: HY931147C-RJ45; HY931147C
U$17: CRYSTAL-GND3X2; CRYSTAL-SMD-3X2

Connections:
1V2A: IC6.4 (1V2A); also elsewhere on the board
1V2D: IC6.13 (1V2D), IC6.22 (1V2D), IC6.31 (1V2D), IC6.45 (1V2D); also elsewhere on the board
1V2O: IC6.14 (1V2O); also elsewhere on the board
3.3V: C29.1, IC6.24 (3V3D), IC6.36 (3V3D), LED3.A, LED4.A, LED7.A, LED8.A, LED9.A, P4.4 (VCC), R9.2, SJ4.2, U1.P$11 (Y+), U1.P$13 (G+); also elsewhere on the board
3V3A: C22.1, IC6.8 (3V3A), IC6.15 (3V3A), U1.P$3 (RXCT), U1.P$4 (TXCT); also elsewhere on the board
5V: IC7.6 (VCC), R14.1, R15.1; also elsewhere on the board
A4_SDA: SJ5.1; also elsewhere on the board
A5_SCL: SJ6.1; also elsewhere on the board
ACTLED: IC6.20 (!ACT), RN1.2 (1)
COLLED: IC6.21 (!COL), RN1.3 (1)
D4: SJ7.2; also elsewhere on the board
D10_CS: IC6.29 (!CS); also elsewhere on the board
D11_MOSI: IC6.32 (MOSI), RN6.6 (2); also elsewhere on the board
D12_MISO: IC6.33 (MISO), P4.7 (DO); also elsewhere on the board
D13_SCK: IC6.30 (SCLK), RN6.7 (2); also elsewhere on the board
FDXLED: IC6.19 (!DPX), RN1.4 (1), RN2.8 (2)
GND: C15.2, C16.2, C22.2, C23.2, C24.2, C29.2, IC6.1 (GNDA), IC6.7 (GNDA), IC6.10 (GND), IC6.16 (GNDA), IC6.23 (GND), IC6.26 (MOD1), IC6.27 (MOD2), IC6.28 (MOD3), IC6.46 (GND), IC7.2 (GND), IC7.4 (A1), IC7.5 (A0), JP3.1 (GND[1]), P4.6 (GND), P4.CD2, P4.GND1 (SHIELD1), P4.GND2 (SHIELD2), R3.1, R7.2, RN8.1, RN8.2 (1), RN8.3 (1), U1.GND1, U1.GND2, U$17.2 (GND), U$17.4 (GND2); also elsewhere on the board
LINKLED: IC6.17 (!LINK), RN2.4 (1), RN2.7 (2)
MODE: IC6.25 (MOD0), R3.2, SJ4.1
unnamed: C24.1, RN5.5 (2), RN5.6 (2)
unnamed: IC7.1 (SCL), R15.2, SJ6.2
unnamed: P4.2 (CS), RN6.4 (1), RN8.8 (2)
unnamed: CD.1, P4.CD1
unnamed: P4.5 (SCK), RN6.2 (1), RN8.7 (2)
unnamed: P4.3 (DI), RN6.3 (1), RN8.6 (2)
unnamed: LED8.C, RN2.6 (2)
unnamed: RN6.5 (2), SJ7.1
unnamed: LED9.C, RN2.5 (2)
unnamed: IC7.3 (SDA), R14.2, SJ5.2
unnamed: C15.1, IC6.11 (XSCO), U$17.1 (XTL1)
unnamed: C16.1, IC6.12 (XSCI), U$17.3 (XTL2)
unnamed: R6.2, R7.1
unnamed: IC6.9 (RSET_BG), R6.1
unnamed: IC6.47 (!INT), R9.1
unnamed: RN2.1, U1.P$14 (G-)
unnamed: JP3.3 (V+[3]), U1.P$9 (V+)
unnamed: JP3.2 (V-[2]), U1.P$10 (V-)
unnamed: C23.1, RN5.7 (2), RN5.8 (2)
unnamed: LED7.C, RN1.5 (2)
unnamed: LED4.C, RN1.6 (2)
unnamed: LED3.C, RN1.7 (2)
unnamed: RN2.2 (1), U1.P$12 (Y-)
RESET: IC6.48 (!RESET); also elsewhere on the board
RXIN: IC6.5 (RXIN), RN5.2 (1), U1.P$2 (RX-)
RXIP: IC6.6 (RXIP), RN5.1, U1.P$1 (RX+)
SPDLED: IC6.18 (!SPD), RN2.3 (1)
TXON: IC6.2 (TXON), RN5.4 (1), U1.P$6 (TX-)
TXOP: IC6.3 (TXOP), RN5.3 (1), U1.P$5 (TX+)
VIN: JP3.4 (VIN[4]); also elsewhere on the board

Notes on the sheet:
Status Display
PoE supply feed to Arduino VIN ->
For DC PoE feed, jumper "+ to VIN", "- to GND" directly
Ethernet Interface with PoE
Open: W6100 (default) Closed: W5500
Wiznet Mode Selection
Ethernet Controller
I2C Addr: 70 (0x50)
uSD_nCS
Micro SD Card Slot
MAC Address ROM

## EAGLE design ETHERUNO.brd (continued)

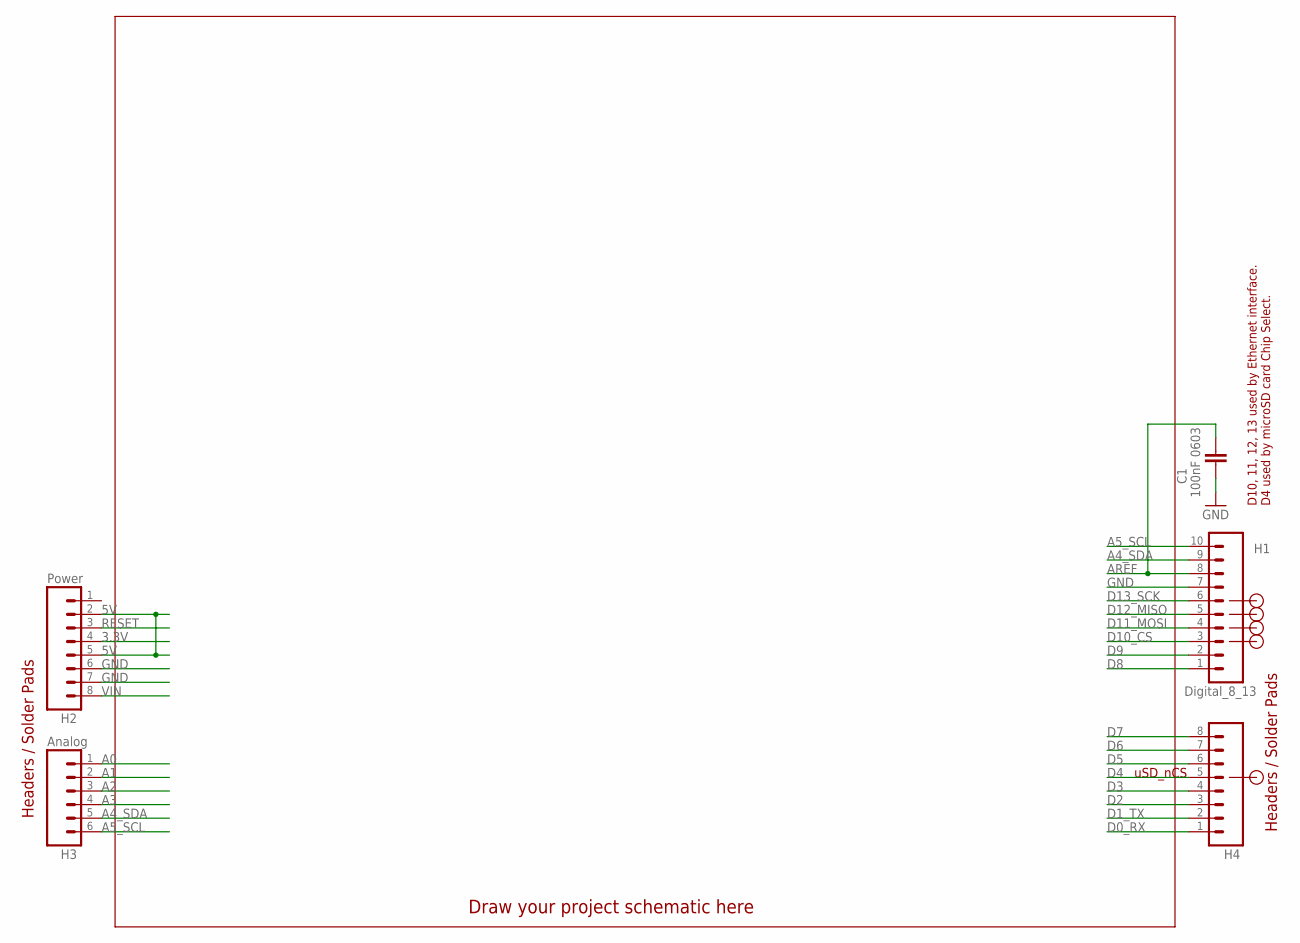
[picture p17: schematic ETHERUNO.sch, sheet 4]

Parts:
C1: 100nF 0603; C0603
H1: Digital_8_13; 1X10-S
H2: Power; 1X08-S
H3: Analog; 1X06-S
H4: Digital_0_7; 1X08-S

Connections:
3.3V: H2.4; also elsewhere on the board
5V: H2.2, H2.5; also elsewhere on the board
A0: H3.1; also elsewhere on the board
A1: H3.2; also elsewhere on the board
A2: H3.3; also elsewhere on the board
A3: H3.4; also elsewhere on the board
A4_SDA: H1.9, H3.5; also elsewhere on the board
A5_SCL: H1.10, H3.6; also elsewhere on the board
AREF: C1.1, H1.8; also elsewhere on the board
D0_RX: H4.1; also elsewhere on the board
D1_TX: H4.2; also elsewhere on the board
D2: H4.3; also elsewhere on the board
D3: H4.4; also elsewhere on the board
D4: H4.5; also elsewhere on the board
D5: H4.6; also elsewhere on the board
D6: H4.7; also elsewhere on the board
D7: H4.8; also elsewhere on the board
D8: H1.1; also elsewhere on the board
D9: H1.2; also elsewhere on the board
D10_CS: H1.3; also elsewhere on the board
D11_MOSI: H1.4; also elsewhere on the board
D12_MISO: H1.5; also elsewhere on the board
D13_SCK: H1.6; also elsewhere on the board
GND: C1.2, H1.7, H2.6, H2.7; also elsewhere on the board
RESET: H2.3; also elsewhere on the board
VIN: H2.8; also elsewhere on the board

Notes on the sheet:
Headers / Solder Pads
Draw your project schematic here
D10, 11, 12, 13 used by Ethernet interface.
uSD_nCS
D4 used by microSD card Chip Select.

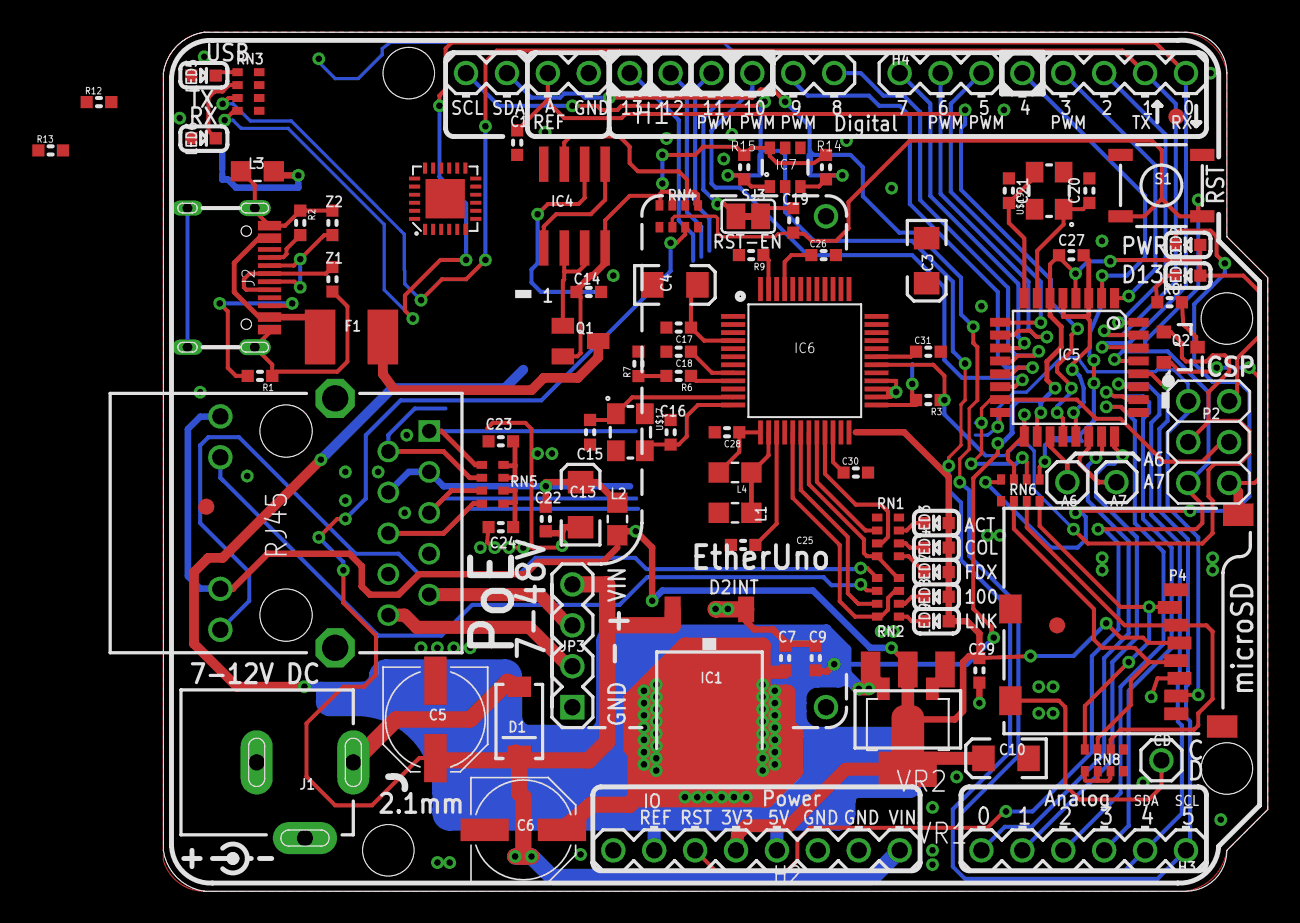
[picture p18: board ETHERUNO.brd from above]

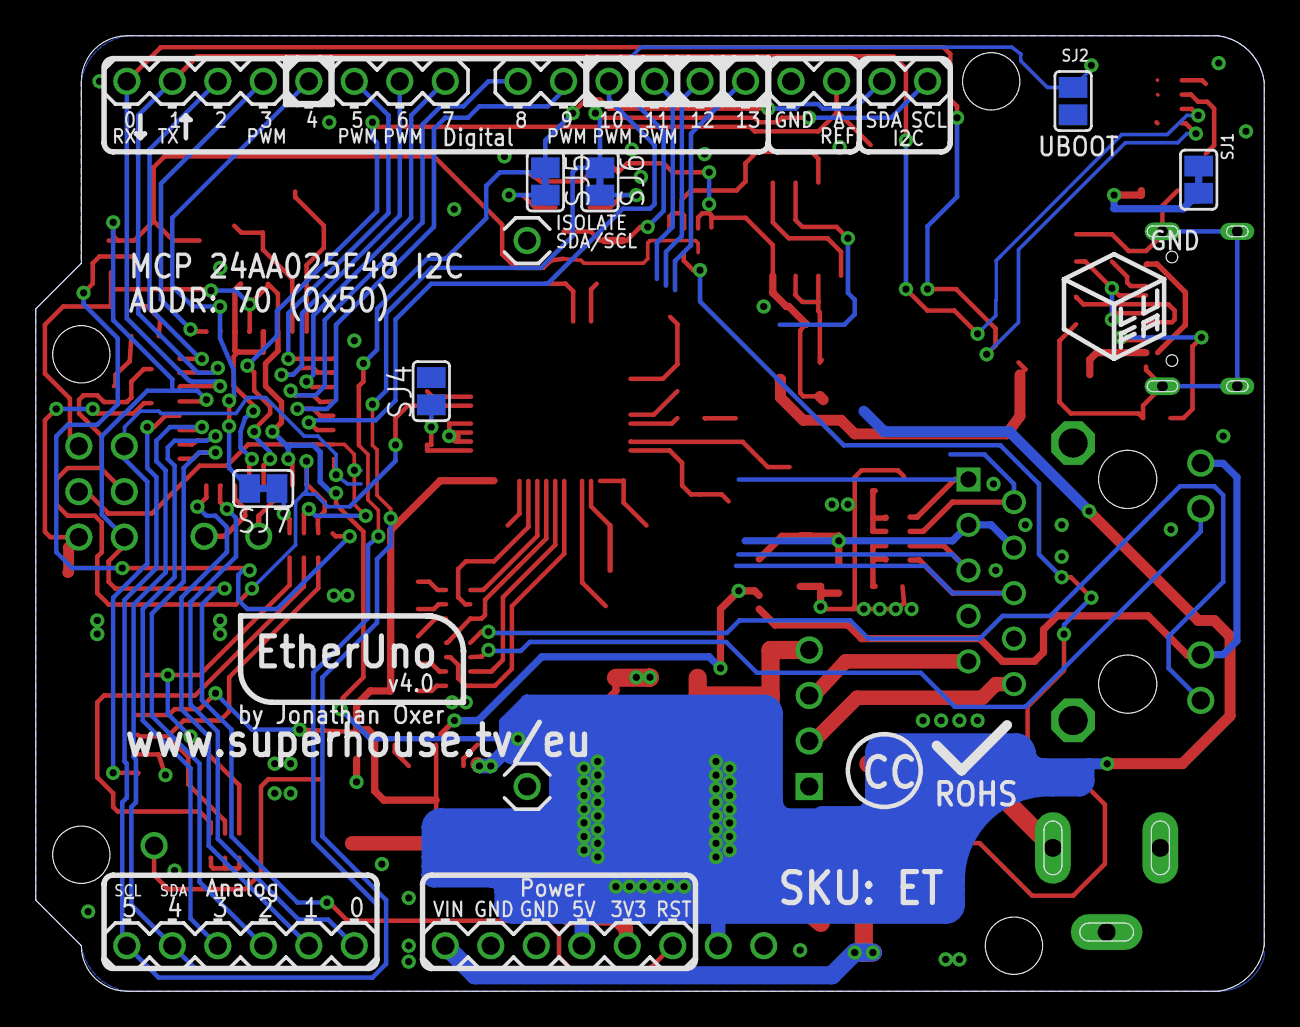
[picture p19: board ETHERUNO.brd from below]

Board: 2 copper layers, 68.6 x 53.3 mm, 98 parts (6 on the bottom side), 91 nets.

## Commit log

2019-04-23 Renamed project files
    [ETHERTEN2.brd, ETHERTEN2.sch]
2019-04-23 Ethernet chip conversion
    [ETHERTEN2.brd, ETHERTEN2.sch]
2020-05-15 Beginning of conversion to USB-C and W5100S
    [ET2.sch, ETHERUNO.brd, ETHERUNO.sch]
2020-05-15 Added cut-track jumper to isolate D4
    [ETHERUNO.brd, ETHERUNO.sch]
2020-05-27 Split schematic into separate sheets
    [ETHERUNO.sch]
2020-07-01 Major rework of schematic to suit W6100
    [ETHERUNO.brd, ETHERUNO.sch]
2020-07-06 Removed ATmega16U2 and added CP2102N for USB-serial conversion
    [ETHERUNO.brd, ETHERUNO.sch]
2020-07-17 Final routing and DRC for v4.0 release
    [ETHERUNO.brd, ETHERUNO.sch]
2020-08-06 Major rework for W5500, ready for v1.0 release
    [ETHERUNO.brd, ETHERUNO.sch]
2020-09-10 Fix Ethernet data line bias resistors. Add strong pullups and pulldowns to mode and RSVD pins. Improve silkscreen. Add diode to PoE VIN to protect against backpower.
    [ETHERUNO.brd, ETHERUNO.sch]
2020-09-17 Added cut-track jumper to isolate D4 from SD_CS
    [ETHERUNO.brd, ETHERUNO.sch]
2020-09-27 Added image of v1.1 prototype.

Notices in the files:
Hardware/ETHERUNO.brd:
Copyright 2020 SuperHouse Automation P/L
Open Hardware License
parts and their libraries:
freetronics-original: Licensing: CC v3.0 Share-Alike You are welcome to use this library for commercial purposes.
